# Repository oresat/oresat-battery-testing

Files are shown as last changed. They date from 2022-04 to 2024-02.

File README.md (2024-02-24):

# oresat-battery-testing

Battery testing software and circuitry for testing cells and batteries to fly on the ISS

V1.0 of the PCB layout:
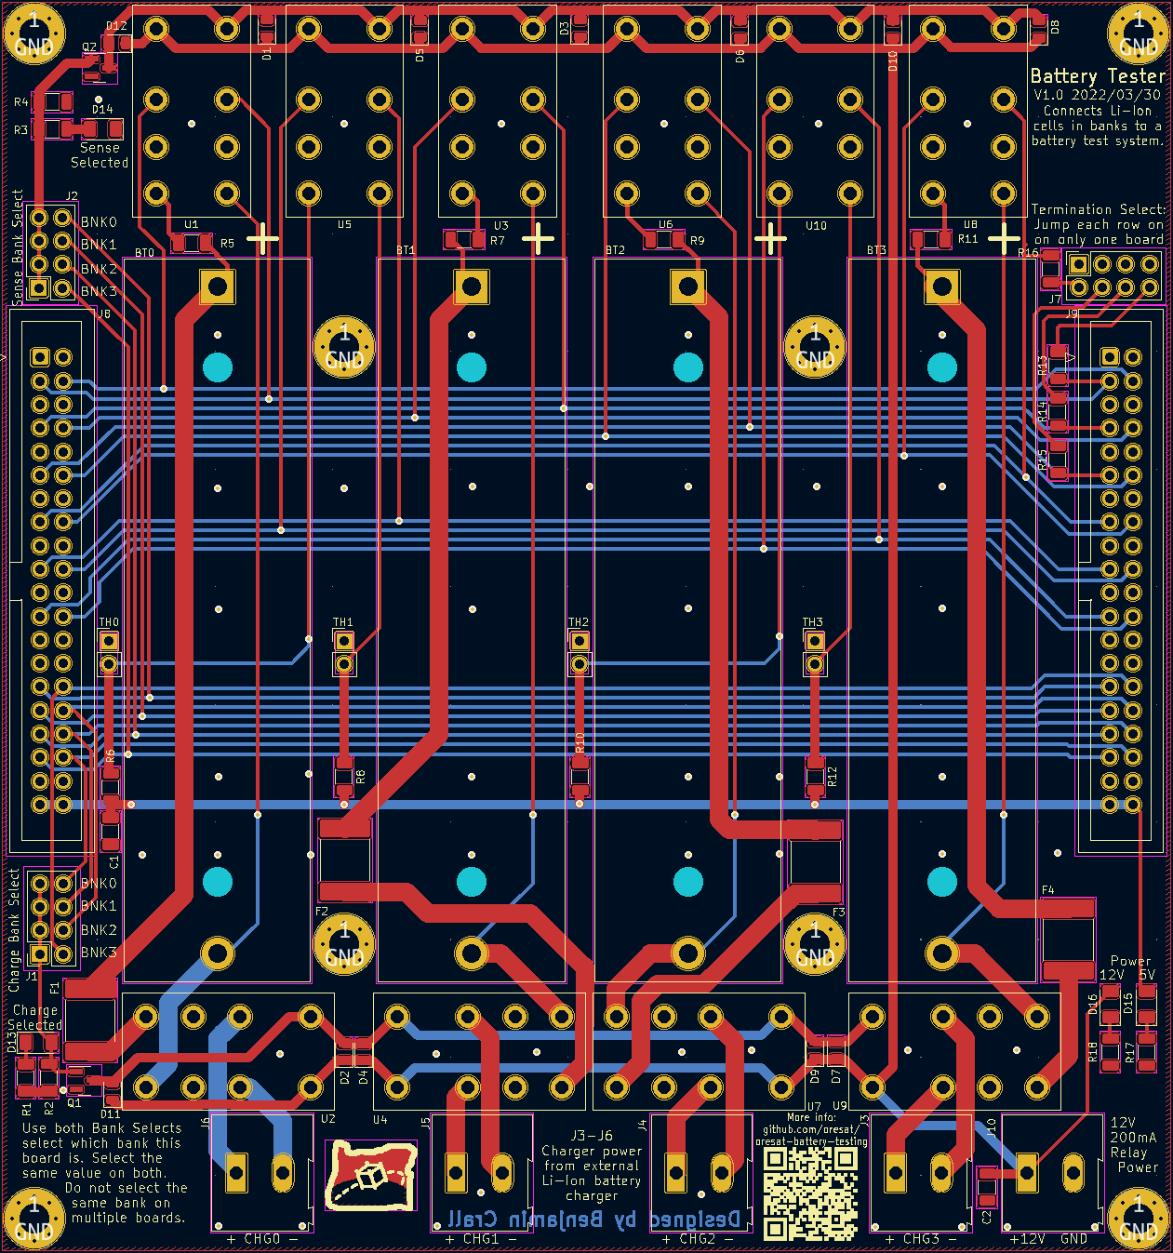
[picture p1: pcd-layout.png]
The PCB layout V1.0


### Software

### Setup
- Clone oresat-battery-testing.
- Install dependencies: `$ sudo apt install libusb-1.0-0-dev pkg-config python3-dev`
- Build Python extension for libb6: `$ make -C libraries`

### Udev Setup
Copy the .rules files (from the Battery Tester folder) into the folder on your computer which contains rules files for udev.

For example on an Ubuntu system: /etc/udev/rules.d

This will allow you to run [filename].py without requiring sudo.

Note that you will have to find the correct devpaths again if you use your own device, then modify 99-b6mini.rules accordingly.

Choose a USB port on your computer to plug the battery board into and do not change it.

### Run
cd main
python battery_test_jig

If you get an import error about libb6:
...run the Makefile in main/libb6 to make an object file.

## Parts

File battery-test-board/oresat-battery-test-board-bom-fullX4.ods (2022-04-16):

OreSat Battery Test Board v1
4 | copies
Qty | Qty Ea | Parts | MFR | MPN | Description | Assembly | STOCK | DIST | DPN | DIST2 | DPN2
16 | 4 | BT0, BT1, BT2, BT3 | MPD (Memory Protection Devices) | BK-18650-PC2 | Battery Holder (Open) 18650 1 Cell PC Pin | TH |  | Digikey | BK-18650-PC2-ND
8 | 2 | C1, C2 | Samsung Electro-Mechanics | CL31A106KAHNNNE | 10 µF ±10% 25V Ceramic Capacitor X5R 1206 (3216 Metric) | SMD |  | Digikey | 1276-1075-1-ND
48 | 12 | D1, D2, D3, D4, D5, D6, D7, D8, D9, D10, D11, D12 | onsemi | NSR05T40P2T5G | Diode Schottky 40 V 500mA (DC) Surface Mount SOD-923 | SMD |  | Digikey | NSR05T40P2T5GOSCT-ND
8 | 2 | D13, D14 | Würth Elektronik | 150120AS75000 | Amber 605nm LED Indication - Discrete 2V 1206 (3216 Metric) | SMD |  | Digikey | 732-4988-1-ND
8 | 2 | D15, D16 | Würth Elektronik | 150120VS75000 | Green 570nm LED Indication - Discrete 2V 1206 (3216 Metric) | SMD |  | Digikey | 732-4993-1-ND
16 | 4 | F1, F2, F3, F4 | Littelfuse Inc. | 2920L100PR | Polymeric PTC Resettable Fuse 33V 1.1 A Ih Surface Mount 2920 (7351 Metric), Concave | SMD |  | Digikey | F2868CT-ND
12 | 3 | J1, J2, J7 | METZ CONNECT USA Inc. | PR20204VBDN | Connector Header Through Hole 8 position 0.100" (2.54mm) | TH |  | Digikey | 1849-PR20204VBDN-ND
20 | 5 | J3, J4, J5, J6, J10 | Adam Tech | EBAA-02-C | 2 Position Wire to Board Terminal Block Horizontal with Board 0.197" (5.00mm) Through Hole | TH |  | Digikey | 2057-EBAA-02-C-ND
8 | 2 | J8, J9 | Würth Elektronik | 732-5401-ND | Connector Header Through Hole 40 position 0.100" (2.54mm) | TH |  | Digikey | 732-5401-ND
8 | 2 | Q1, Q2 | Panjit International Inc. | PJA3412-AU_R1_000A1 | N-Channel 20 V 4.1A (Ta) 1.25W (Ta) Surface Mount SOT-23k | SMD |  | Digikey | 3757-PJA3412-AU_R1_000A1CT-ND
12 | 3 | R1, R3, R17 | Stackpole Electronics Inc | RMCF1206FT4K70 | 4.7 kOhms ±1% 0.25W, 1/4W Chip Resistor 1206 (3216 Metric) Automotive AEC-Q200 Thick Film | SMD |  | Digikey | RMCF1206FT4K70CT-ND
12 | 3 | R2, R4, R18 | Stackpole Electronics Inc | RMCF1206FT10K0 | 10 kOhms ±1% 0.25W, 1/4W Chip Resistor 1206 (3216 Metric) Automotive AEC-Q200 Thick Film | SMD |  | Digikey | RMCF1206FT10K0CT-ND
16 | 4 | R5, R7, R9, R11 | Stackpole Electronics Inc | RMCF1206FT470R | 470 Ohms ±1% 0.25W, 1/4W Chip Resistor 1206 (3216 Metric) Automotive AEC-Q200 Thick Film | SMD |  | Digikey | RMCF1206FT470RCT-ND
16 | 4 | R6, R8, R10, R12 | Stackpole Electronics Inc | RMCF1206FT510K | 510 kOhms ±1% 0.25W, 1/4W Chip Resistor 1206 (3216 Metric) Automotive AEC-Q200 Thick Film | SMD |  | Digikey | RMCF1206FT510KCT-ND
16 | 4 | R13, R14, R15, R16 | Stackpole Electronics Inc | RMCF1206FT1M00 | 1 MOhms ±1% 0.25W, 1/4W Chip Resistor 1206 (3216 Metric) Automotive AEC-Q200 Thick Film | SMD |  | Digikey | RMCF1206FT1M00CT-ND
16 | 4 | TH0, TH1, TH2, TH3 | Murata Electronics | NXFT15XH103FA1B025 | NTC Thermistor 10k Bead | TH |  | Digikey | 490-12817-ND
40 | 10 | U1, U2, U3, U4, U5, U6, U7, U8, U9, U10 | CIT Relay and Switch | J104D2C12VDC.15S‎ | General Purpose Relay DPDT | TH |  | Digikey | 2449-J104D2C12VDC.15S-ND
4 |  |  | SkyRC | B6Mini | Li-Ion battery charger/discharger with computer control |  |  | Walmart | https://www.walmart.com/ip/SKYRC-iMAX-B6-Mini-DC-Power-Professional-Balance-Charger-Discharger/999792861 | RC-Wing | https://www.rc-wing.com/imax-b6-mini-charger.html
1 |  |  | Atolla | CH-207U3 | Powered USB Hub 7.0 7 port |  |  | Amazon | B07G8CMR18
1 |  |  | EZON | 4350280033 | AC/DC Power Supply, AC 100V/240V to DC 12V 10A 120W |  |  | Amazon | B01E6RMASC

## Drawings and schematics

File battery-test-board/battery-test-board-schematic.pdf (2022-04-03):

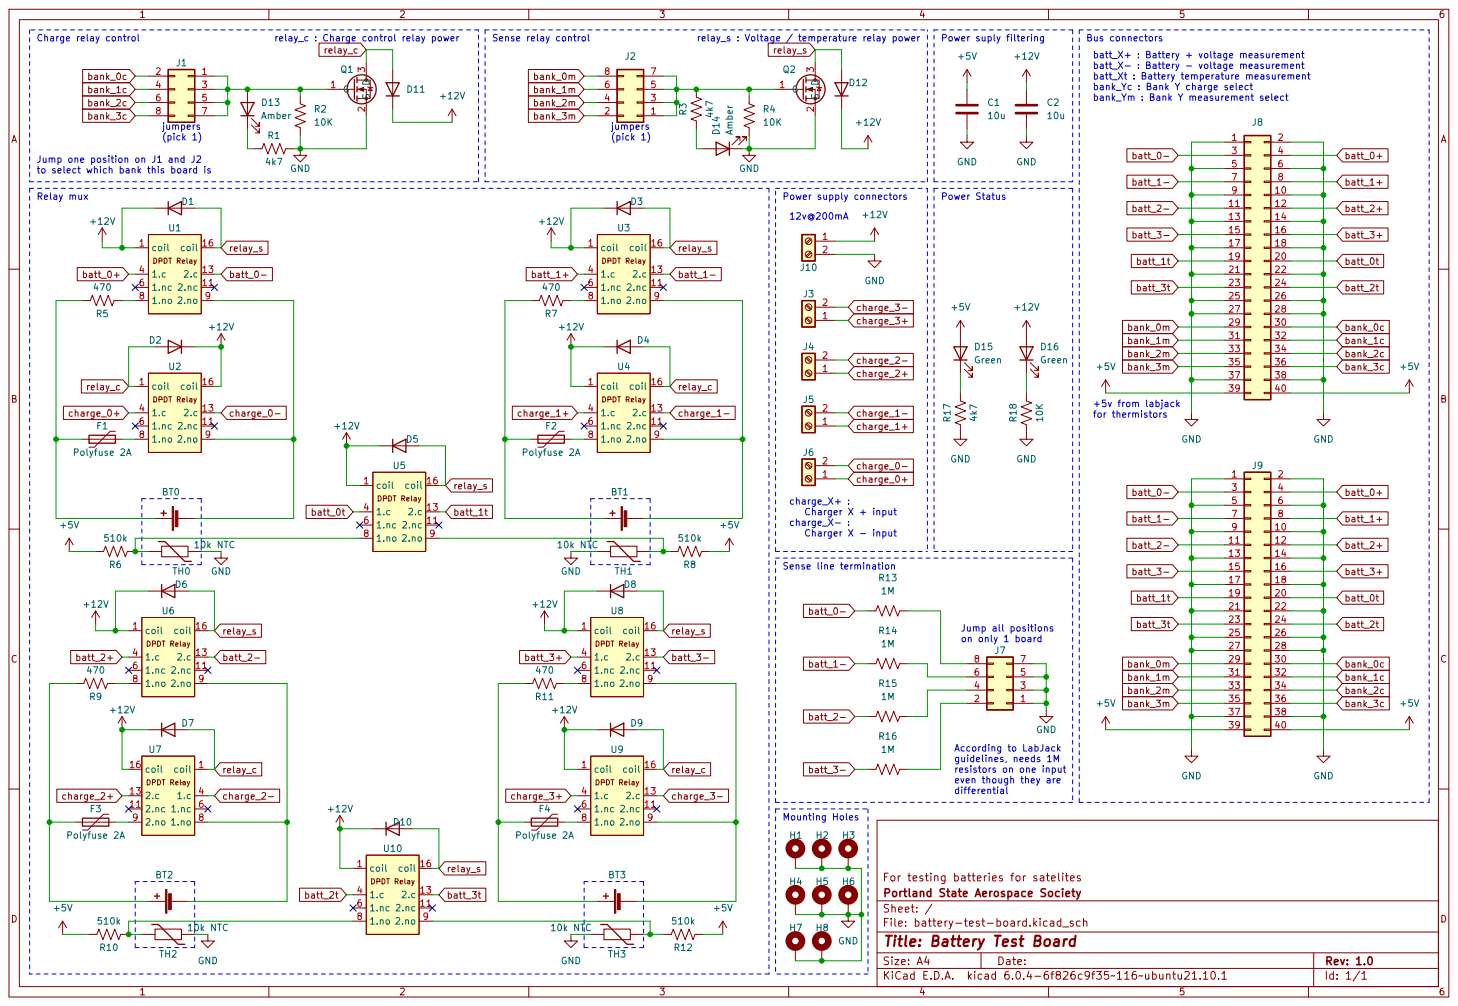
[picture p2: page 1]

for thermistors Power Status Sense relay control

bank_Yc : Bank Y charge select bank_Ym : Bank Y measurement select charge_X+ :

Jump one position on J1 and J2

Relay mux

on only 1 board Sense line termination Power supply connectors 12v@200mA

For testing batteries for satelites GND

According to LabJack
guidelines, needs 1M
resistors on one input
even though they are
differential

File: battery-test-board.kicad_sch Sheet: / Portland State Aerospace Society

Id: 1/1 Title: Battery Test Board

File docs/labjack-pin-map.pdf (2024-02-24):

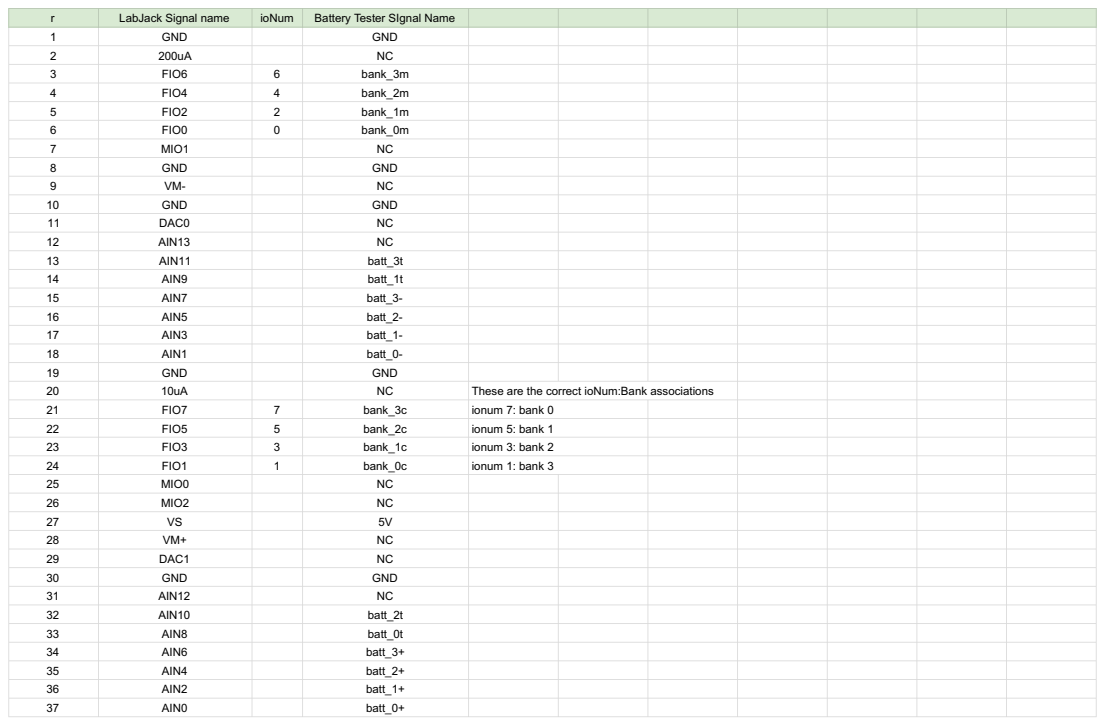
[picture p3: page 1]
LabJack Signal name; ioNum; Battery Tester SIgnal Name; GND; FIO6; bank_3m; FIO4; bank_2m; FIO2; bank_1m; FIO0; bank_0m; MIO1; DAC0; AIN13; AIN11; batt_3t; AIN9; batt_1t; AIN7; batt_3-; AIN5; batt_2-; AIN3; batt_1-; AIN1; batt_0-; These are the correct ioNum:Bank associations; FIO7; bank_3c; ionum 7: bank 0; FIO5; bank_2c; ionum 5: bank 1; FIO3; bank_1c; ionum 3: bank 2; FIO1; bank_0c; ionum 1: bank 3; MIO0; MIO2; DAC1; AIN12; AIN10; batt_2t; AIN8; batt_0t; AIN6; batt_3+; AIN4; batt_2+; AIN2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

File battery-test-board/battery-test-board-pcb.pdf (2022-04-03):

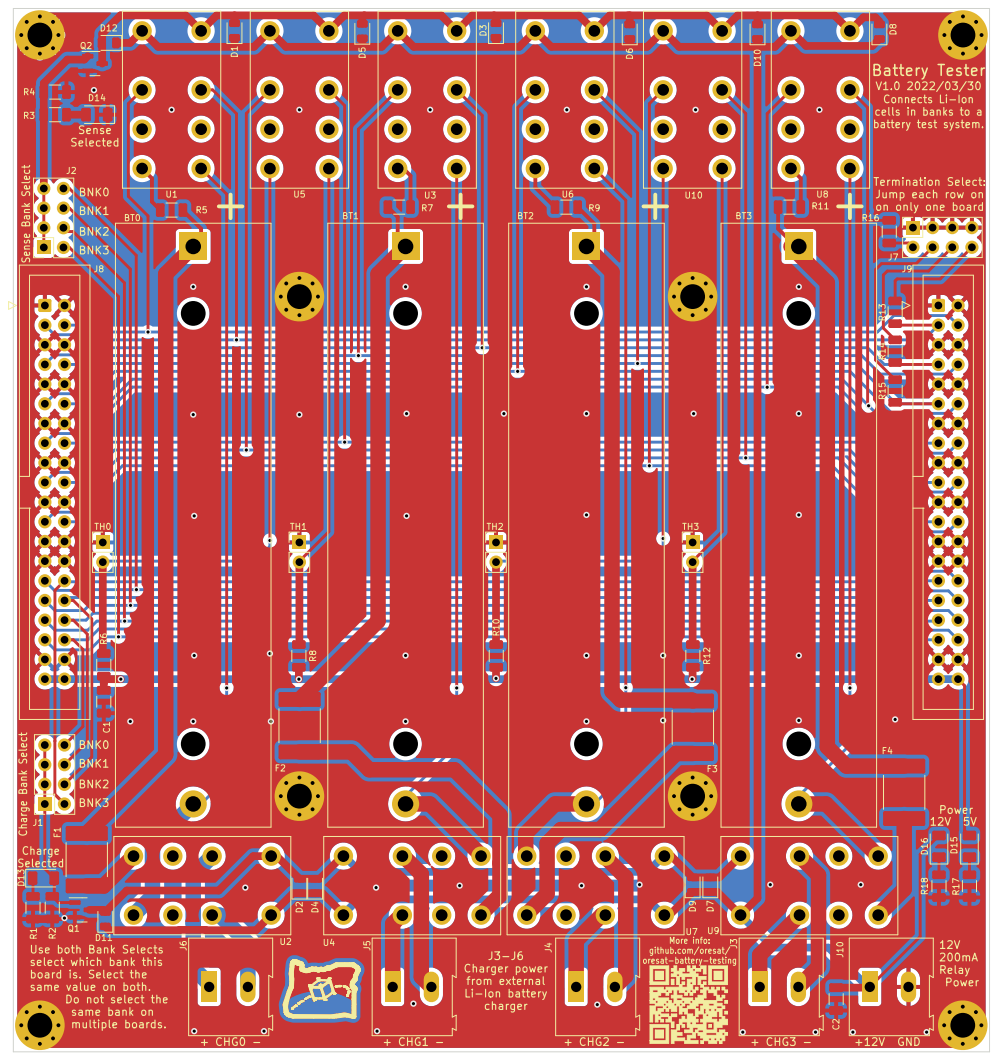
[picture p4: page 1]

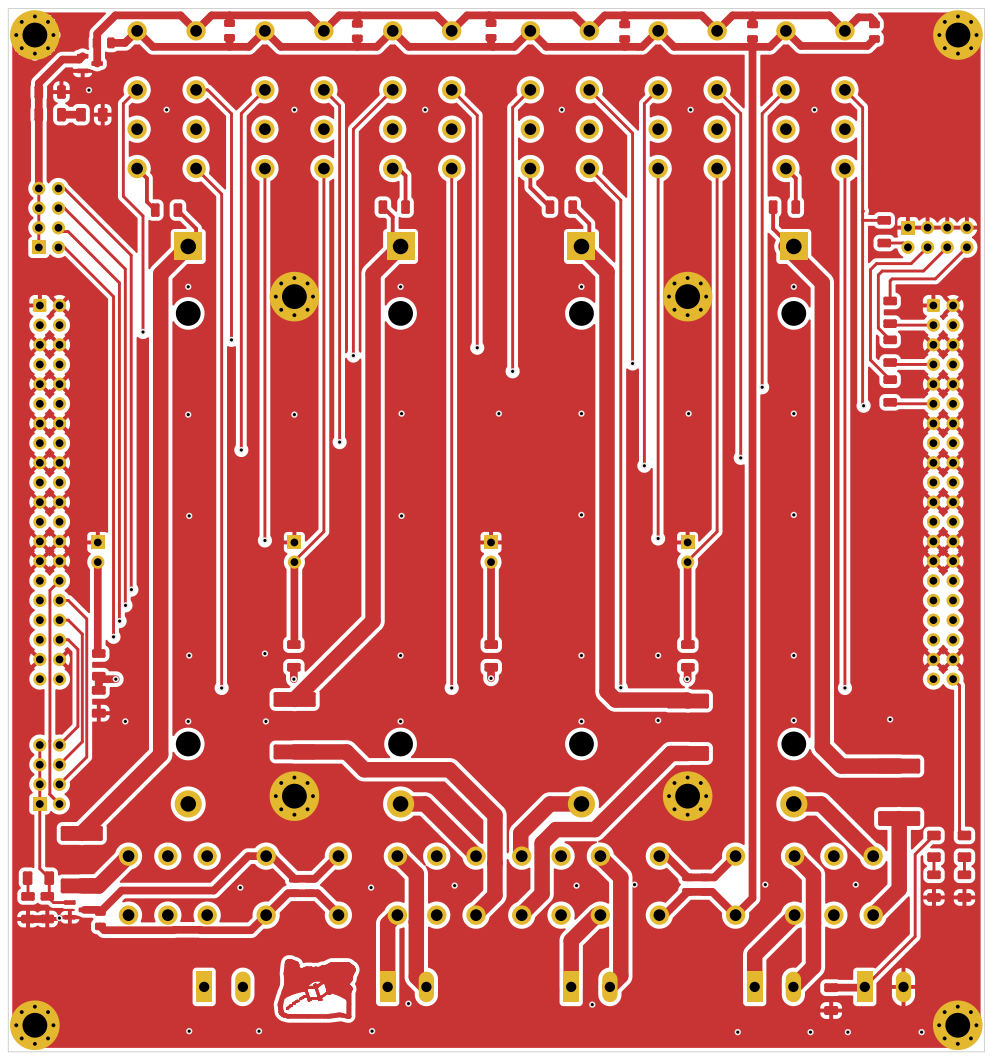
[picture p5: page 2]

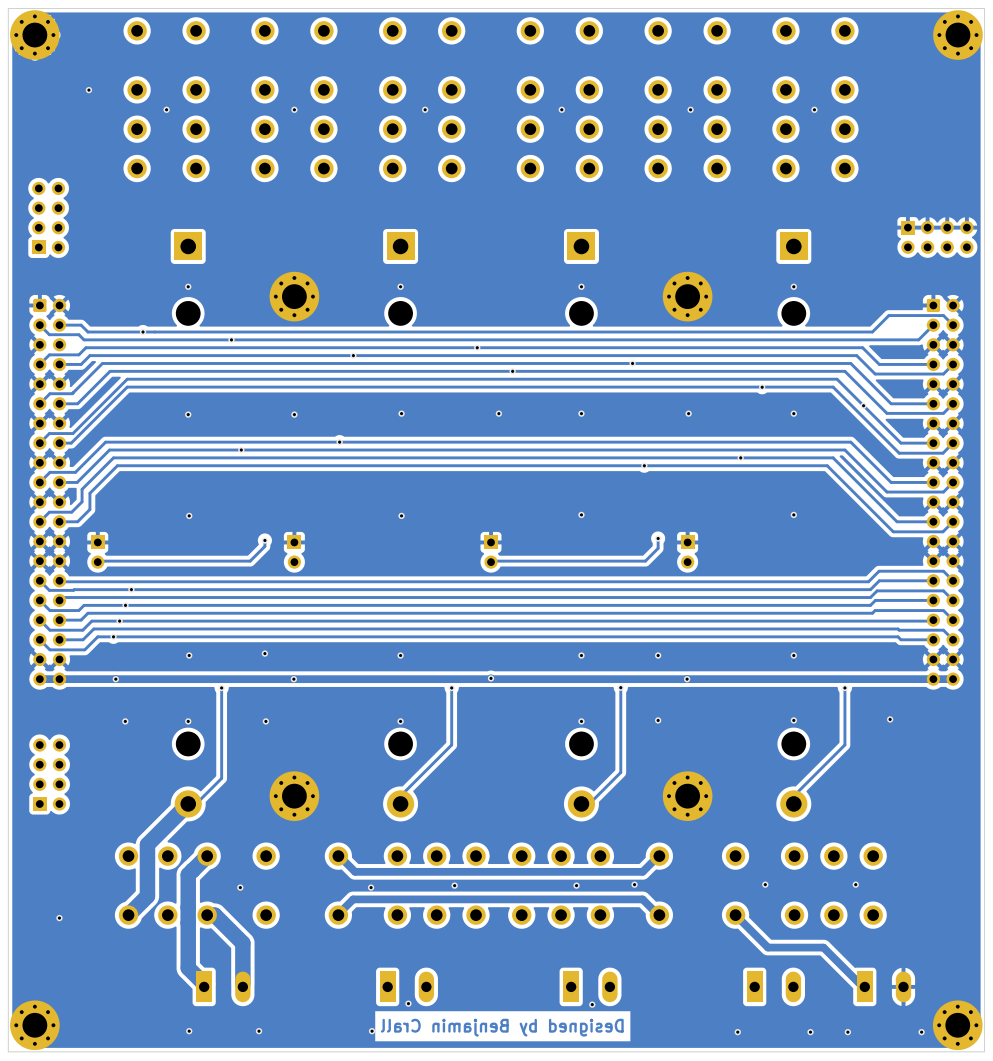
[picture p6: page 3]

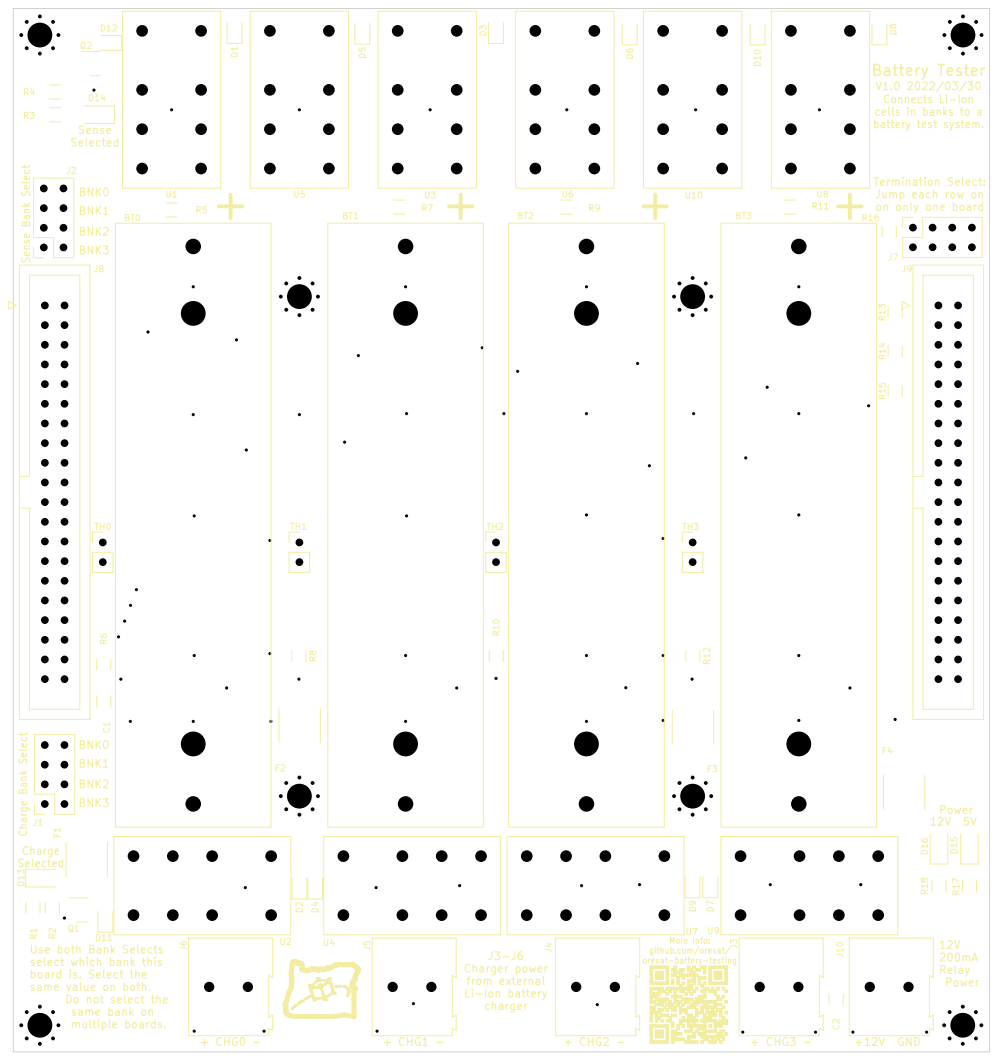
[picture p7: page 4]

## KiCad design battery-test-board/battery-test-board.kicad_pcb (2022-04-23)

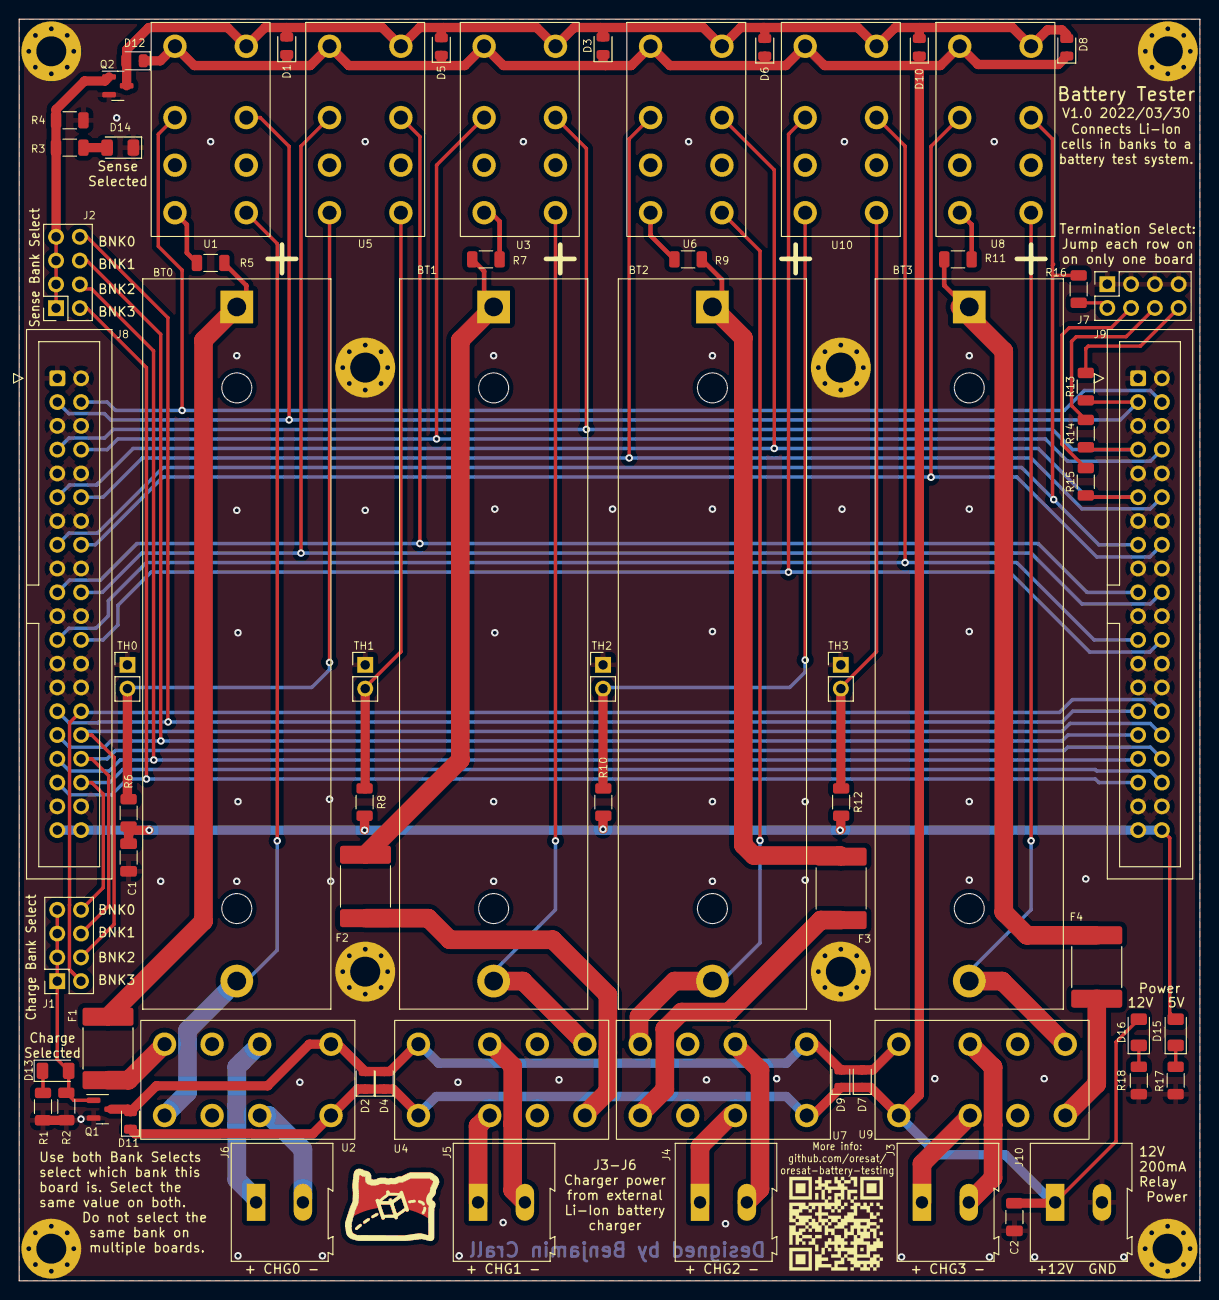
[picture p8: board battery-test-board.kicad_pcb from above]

Board: 2 copper layers, 126.1 x 134.7 mm, 78 parts (0 on the bottom side), 63 nets.

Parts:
BT0, BT1, BT2, BT3: battery; BatteryHolder_MPD_BH-18650-PC2
C1, C2: 10u; C_1206_3216Metric
D1, D2, D3, D4, D5, D6, D7, D8, D9, D10, D11, D12: diode; D_0805_2012Metric
D13, D14: Amber; LED_1206_3216Metric
D15, D16: Green; LED_1206_3216Metric
F1, F2, F3, F4: Polyfuse 2A; Fuse_2920_7451Metric
H1, H2, H3, H4, H5, H6, H7, H8: MountingHole_Pad; MountingHole_3.2mm_M3_Pad_Via
J1, J2, J7: Conn_02x04_Odd_Even; PinSocket_2x04_P2.54mm_Vertical
J3, J4, J5, J6, J10: Screw_Terminal_01x02; TerminalBlock_Altech_AK300-2_P5.00mm
J8, J9: connector; IDC-Header_2x20_P2.54mm_Vertical
Q1, Q2: mosfet; SOT-23
R1, R3, R17: 4k7; R_1206_3216Metric
R2, R4, R18: 10K; R_1206_3216Metric
R5, R7, R9, R11: 470; R_1206_3216Metric
R6, R8, R10, R12: 510k; R_1206_3216Metric
R13, R14, R15, R16: 1M; R_1206_3216Metric
TH0, TH1, TH2, TH3: Thermistor; thermister-solderin
U1, U2, U3, U4, U5, U6, U7, U8, U9, U10: relay; relay-dpdt-.3in

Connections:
+5V: C1.1, D15.2 (A), J8.39, J8.40, J9.39, J9.40, R6.1, R8.2, R10.1, R12.2
+12V: C2.1, D1.1 (K), D2.1 (K), D3.1 (K), D4.1 (K), D5.1 (K), D6.1 (K), D7.1 (K), D8.1 (K), D9.1 (K), D10.1 (K), D11.1 (K), D12.1 (K), D16.2 (A), J10.1, U1.1 (coil), U2.16 (coil), U3.1 (coil), U4.1 (coil), U5.1 (coil), U6.1 (coil), U7.16 (coil), U8.1 (coil), U9.1 (coil), U10.1 (coil)
GND: C1.2, C2.2, D14.1 (K), H1.1, H2.1, H3.1, H4.1, H5.1, H6.1, H7.1, H8.1, J7.1, J7.3, J7.5, J7.7, J8.1, J8.2, J8.5, J8.6, J8.9, J8.10, J8.13, J8.14, J8.17, J8.18, J8.21, J8.22, J8.25, J8.26, J8.27, J8.28, J8.37, J8.38, J9.1, J9.2, J9.5, J9.6, J9.9, J9.10, J9.13, J9.14, J9.17, J9.18, J9.21, J9.22, J9.25, J9.26, J9.27, J9.28, J9.37, J9.38, J10.2, Q1.2 (S), Q2.2 (S), R1.1, R2.2, R4.2, R17.2, R18.2, TH0.1, TH1.1, TH2.1, TH3.1
unnamed: BT0.1 (+), F1.1, R5.1
unnamed: BT0.2 (-), U1.9 (2.no), U2.9 (2.no)
unnamed: BT1.1 (+), F2.1, R7.1
unnamed: BT1.2 (-), U3.9 (2.no), U4.9 (2.no)
unnamed: BT2.1 (+), F3.1, R9.1
unnamed: BT2.2 (-), U6.9 (2.no), U7.8 (1.no)
unnamed: BT3.1 (+), F4.1, R11.1
unnamed: BT3.2 (-), U8.9 (2.no), U9.9 (2.no)
unnamed: D13.1 (K), R1.2
unnamed: D13.2 (A), J1.1, J1.3, J1.5, J1.7, Q1.1 (G), R2.1
unnamed: D14.2 (A), R3.2
unnamed: D15.1 (K), R17.1
unnamed: D16.1 (K), R18.1
unnamed: F1.2, U2.8 (1.no)
unnamed: F2.2, U4.8 (1.no)
unnamed: F3.2, U7.9 (2.no)
unnamed: F4.2, U9.8 (1.no)
unnamed: J2.1, J2.3, J2.5, J2.7, Q2.1 (G), R3.1, R4.1
unnamed: J7.2, R16.1
unnamed: J7.4, R15.2
unnamed: J7.6, R14.2
unnamed: J7.8, R13.2
unnamed: R5.2, U1.8 (1.no)
unnamed: R6.2, TH0.2, U5.8 (1.no)
unnamed: R7.2, U3.8 (1.no)
unnamed: R8.1, TH1.2, U5.9 (2.no)
unnamed: R9.2, U6.8 (1.no)
unnamed: R10.2, TH2.2, U10.8 (1.no)
unnamed: R11.2, U8.8 (1.no)
unnamed: R12.1, TH3.2, U10.9 (2.no)
bank_0c: J1.2, J8.30, J9.30
bank_0m: J2.8, J8.29, J9.29
bank_1c: J1.4, J8.32, J9.32
bank_1m: J2.6, J8.31, J9.31
bank_2c: J1.6, J8.34, J9.34
bank_2m: J2.4, J8.33, J9.33
bank_3c: J1.8, J8.36, J9.36
bank_3m: J2.2, J8.35, J9.35
batt_0+: J8.4, J9.4, U1.4 (1.c)
batt_0-: J8.3, J9.3, R13.1, U1.13 (2.c)
batt_0t: J8.20, J9.20, U5.4 (1.c)
batt_1+: J8.8, J9.8, U3.4 (1.c)
batt_1-: J8.7, J9.7, R14.1, U3.13 (2.c)
batt_1t: J8.19, J9.19, U5.13 (2.c)
batt_2+: J8.12, J9.12, U6.4 (1.c)
batt_2-: J8.11, J9.11, R15.1, U6.13 (2.c)
batt_2t: J8.24, J9.24, U10.4 (1.c)
batt_3+: J8.16, J9.16, U8.4 (1.c)
batt_3-: J8.15, J9.15, R16.2, U8.13 (2.c)
batt_3t: J8.23, J9.23, U10.13 (2.c)
charge_0+: J6.1, U2.4 (1.c)
charge_0-: J6.2, U2.13 (2.c)
charge_1+: J5.1, U4.4 (1.c)
charge_1-: J5.2, U4.13 (2.c)
charge_2+: J4.1, U7.13 (2.c)
charge_2-: J4.2, U7.4 (1.c)
charge_3+: J3.1, U9.4 (1.c)
charge_3-: J3.2, U9.13 (2.c)
relay_c: D2.2 (A), D4.2 (A), D7.2 (A), D9.2 (A), D11.2 (A), Q1.3 (D), U2.1 (coil), U4.16 (coil), U7.1 (coil), U9.16 (coil)
relay_s: D1.2 (A), D3.2 (A), D5.2 (A), D6.2 (A), D8.2 (A), D10.2 (A), D12.2 (A), Q2.3 (D), U1.16 (coil), U3.16 (coil), U5.16 (coil), U6.16 (coil), U8.16 (coil), U10.16 (coil)

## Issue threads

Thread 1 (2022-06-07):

Specified diodes are the wrong size

Benjamin-C, 2022-06-07:
The diodes specified in the BOM are smaller than the footprints on the board and smaller than they need to be. They should be replaced with a larger version

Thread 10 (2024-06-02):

Dev Path issue AGAIN!

ThePakkrat, 2024-06-02:
Program finds first charger but no others, or perhaps it no longer runs through each serial path.

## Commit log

2022-02-25 Created V1.0 of the battery test board
    [battery-test-board.kicad_pcb, battery-test-board.kicad_sch]
2022-02-25 Added pdf schematic and PCB layout
    [battery-test-board.kicad_pcb]
2022-02-25 Added pretty board layout picture
2022-03-29 Updated footprints and PCB
    [battery-test-board.kicad_pcb, battery-test-board.kicad_sch]
2022-03-31 Fixed silk screen and a few other things
    [battery-test-board.kicad_pcb, battery-test-board.kicad_sch]
2022-03-31 Finished BOM
    [battery-test-board.kicad_pcb, battery-test-board.kicad_sch]
2022-03-31 Changed silkscreen
    [battery-test-board.kicad_pcb]
2022-04-01 Added sticker
    [battery-test-board.kicad_pcb]
2022-04-01 Made stuff prettier
    [battery-test-board.kicad_pcb]
2022-04-02 Fixed many little issues
    [battery-test-board.kicad_pcb, battery-test-board.kicad_sch]
2022-04-03 Fixed a few issues missed last time
    [battery-test-board.kicad_pcb, battery-test-board.kicad_sch]
2022-04-03 Added BOM
    [oresat-battery-test-board-bom.ods]
2022-04-03 Updated schematic PDF
2022-04-03 Updated PCB image and PDF
    [battery-test-board.kicad_pcb]
2022-04-23 No changes to PCB; just changes to plotting settings.
    [battery-test-board.kicad_pcb]
2022-04-23 Updated .gitignore for kicad 6 and for psas temporary folders
2022-07-24 Added labjack adapter board
    [labjack-connector.kicad_pcb, labjack-connector.kicad_sch]
2022-07-25 Adjusted to OSH Park manufacturing
    [labjack-connector.kicad_pcb]
2022-07-25 LabJack<->test boards adapter board ready to go
    [labjack-connector.kicad_pcb]
2022-07-25 Added part number
    [labjack-connector.kicad_pcb, labjack-connector.kicad_sch]
2022-08-23 Added some library source code for the chargers
2023-07-02 current test phase
2023-07-14 Uncommented code that throws error in Device.cc in libb6.
2023-07-21 added udev rule for charger USBs, added notes document for my personal use (but I'll commit it so that others can see where I'm at)
2023-09-01 trying to fix Device.cc (and added temp_file to test things); stoi isn't working
2023-09-17 can now talk to one charger at a time, seg fault occurs when opening more than one
2023-09-17 cleaned up directory, commented out last line of destructor in Device.cc which causes seg fault, without it there will be memory leaks
2023-09-20 I shall clean up the repo!
    [battery-test-board.kicad_pcb, battery-test-board.kicad_sch, labjack-connector.kicad_pcb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]
2023-09-20 more cleansing
    [oresat-battery-test-board-bom.ods]
2023-09-24 .cc/.cpp to libb6 in battery_tester, dashes become underscores
2023-10-30 added minor error check in Device.cc line 132, currently do not get seg fault while plugged in
2023-12-04 Fixing things, but not done yet. Weird error where print statements that are deleted or commented out in Device.cc still get printed to the screen... A ghost?
2023-12-18 Added test directory for pytest, going through the components of labjack at current moment
2023-12-25 added .ods file extension to file in hardware-specs, successfully can talk to Charger B (need to redo udev rules for all other chargers, then redo documentation for all)
    [oresat-battery-test-board-bom-fullX4.ods]
2023-12-25 Charger B works, mostly!
2024-01-08 new_folder/measure.py edits: charger B can touch batteries, labjack can also read info from batteries in bank 3, about 1/8 of my board works, but it's really cool nonetheless
2024-01-08 Hehey! Have questions. Current Questions: Is the voltage and temperature data accurate (it does change depending on whether batteries are in bank versus not, but it has negative numbers which is weir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
2024-02-19 Can now select sense pins on any charger. Get the correct voltage readings.
2024-02-19 All charge pins now work! Turns out they are the reverse of what was in the labjack documet (i.e. must go 7/5/3/1 for 0/1/2/3 rather than for 3/2/1/0 as was written prior
2024-02-19 Added labjack pin map pdf to folder. It will need to be re-added if it gets updated but that is unlikely.
2024-02-24 Almost done making PR changes.
    [battery-test-board.kicad_pcb, battery-test-board.kicad_sch, labjack-connector.kicad_pcb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]
2024-02-24 Adding kicad files back.
2024-02-24 Removed temporary kicad files.
